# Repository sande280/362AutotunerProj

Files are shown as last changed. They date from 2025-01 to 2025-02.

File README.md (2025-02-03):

# Final Demo Video Link: https://youtube.com/shorts/DRTG0014v1s?feature=share

# Autotune and the Microcontrollers

## Project Description
- Display the frequency of the input wave and output wave using the OLED display and SPI.
- Display the autotuned note using the 7-SEG display and SPI with DMA.
- Match the read data to the nearest musical note, and output the audio via the DAC.
- Read data from earbud microphone and convert data into a single sinusoidal wave using ADC.
- Additionally, keep latency within a reasonable amount such that the process is imperceptible or nearly.

## Schematic
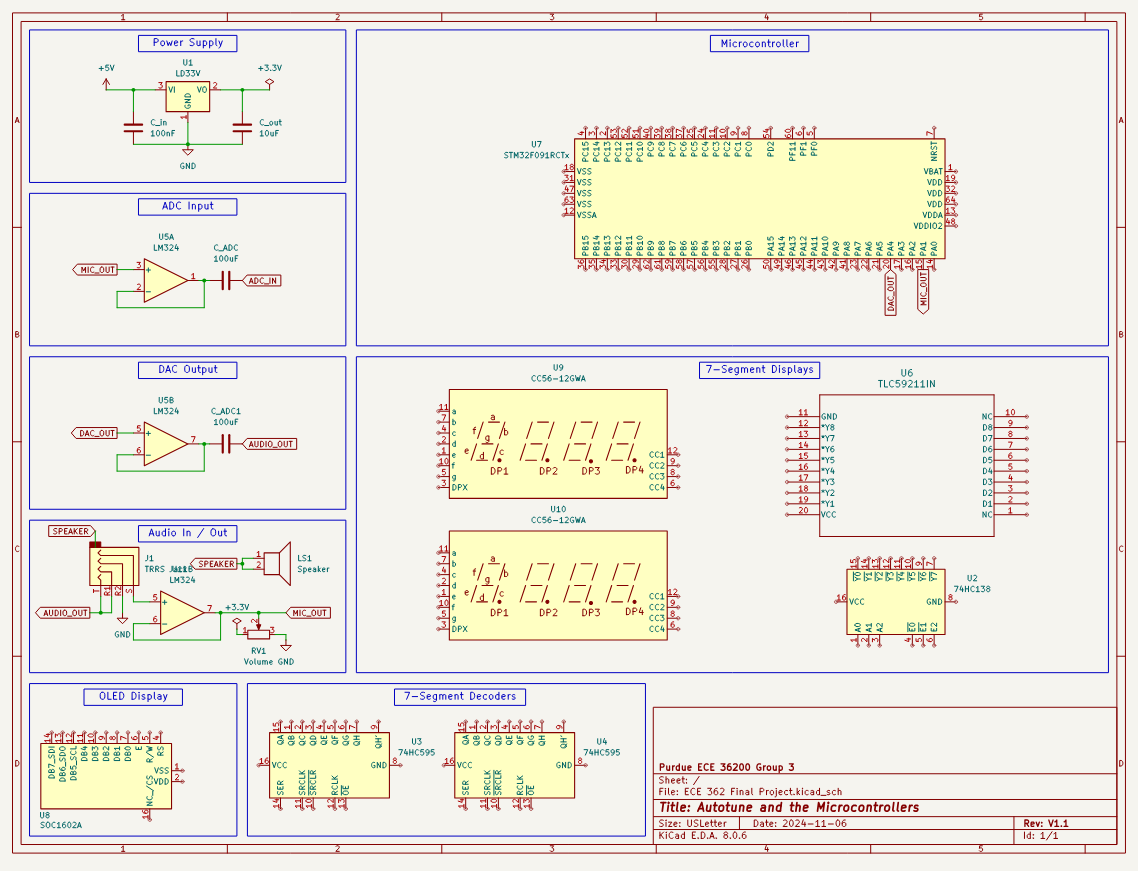
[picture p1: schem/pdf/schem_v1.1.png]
microcontroller-based autotune schematic Autotune and the Microcontrollers Schematic


## Main Features
Using the microphone on a pair of wired earbuds, we will input an audio signal (such as humming) into the ADC of the STM32. There, the microcontroller will find the nearest musical note (closest to the input frequency) and output that via the DAC to a speaker. We will also output frequency information on the OLED display, and note information on a 7-segment display.
- STM32 microcontroller
- Audio / headphone jack
- Wired headphones with mic
- Lab 4 DAC/ADC breadboard setup
- 7-segment displays
- OLED display

## External Interfaces
- SPI
- GPIO

## Internal Peripherals
- DMA
- ADC
- DAC
- SPI

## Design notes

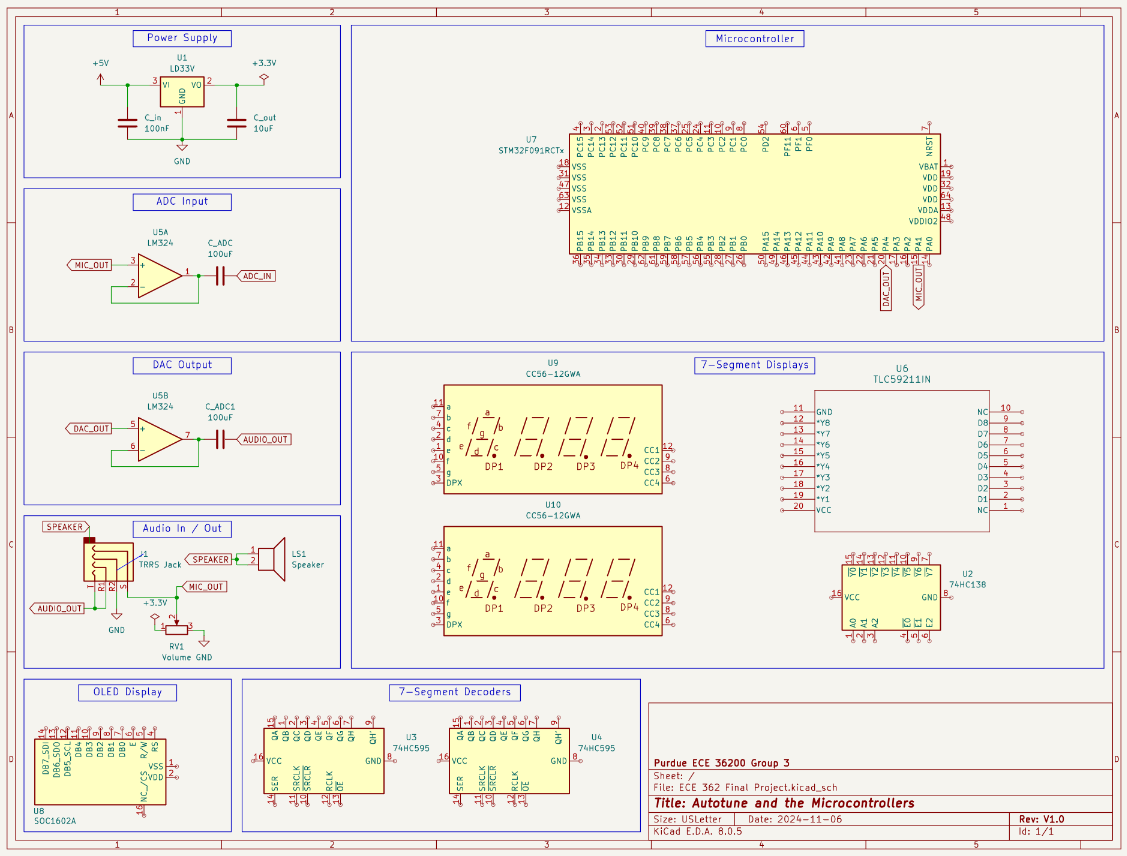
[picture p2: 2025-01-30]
schem/pdf/schem_v1.png

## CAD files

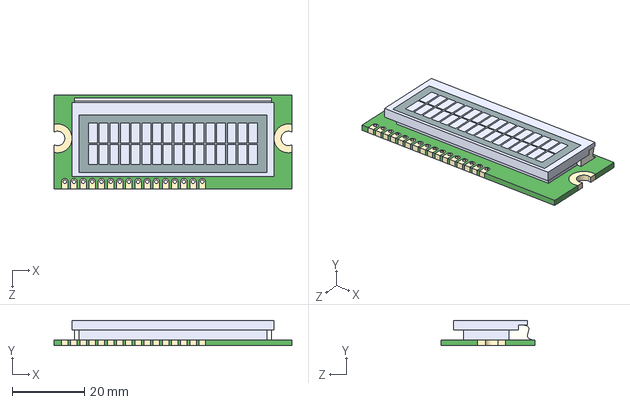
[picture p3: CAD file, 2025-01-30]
schem/KiCad Symbols/LCM_S01602DTR_M/LCM-S01602DTR_M.step
66.0 x 7.00 x 26.0 mm

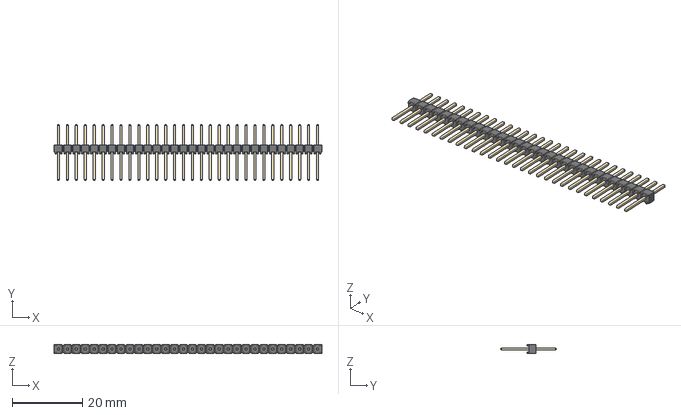
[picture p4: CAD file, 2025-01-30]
schem/KiCad Symbols/stm32f091-ref/models/HTSW-130-22-T-S.FCStd
76.2 x 16.0 x 2.49 mm
_HTSW-130-22-T-S_body
_T-1S6-15-HTSW-1--22-30-S

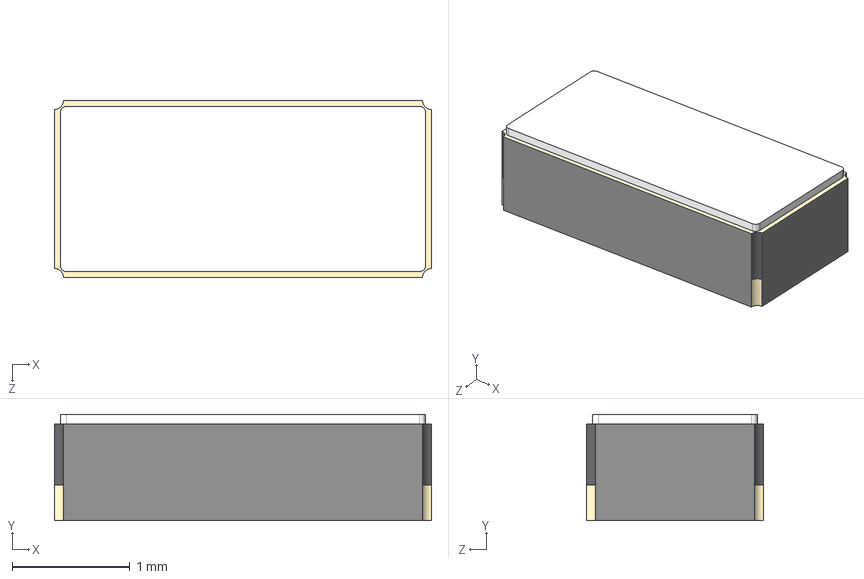
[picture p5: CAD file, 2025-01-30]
schem/KiCad Symbols/stm32f091-ref/models/ECX-.327-CDX-1293.step
3.20 x 0.9 x 1.50 mm

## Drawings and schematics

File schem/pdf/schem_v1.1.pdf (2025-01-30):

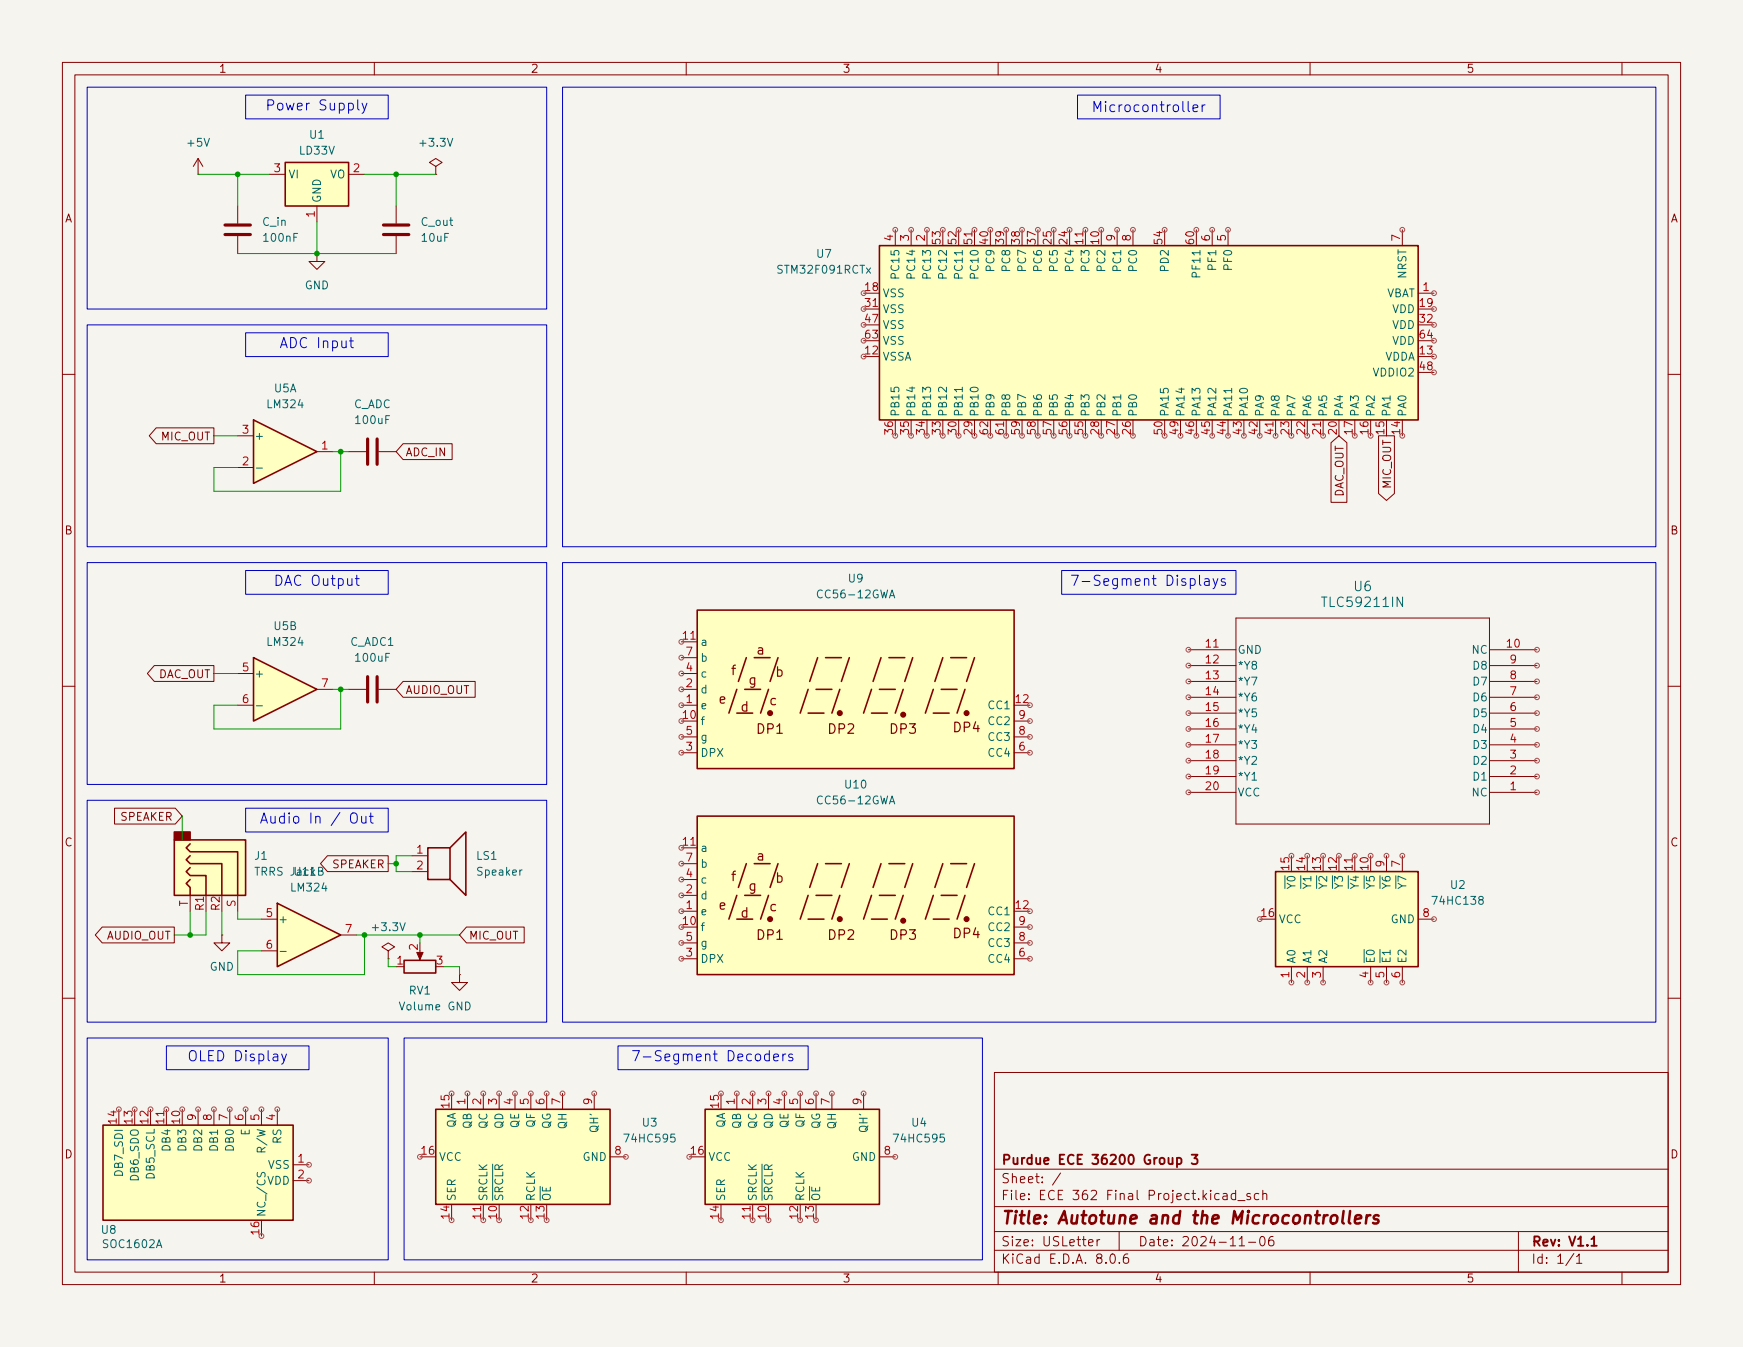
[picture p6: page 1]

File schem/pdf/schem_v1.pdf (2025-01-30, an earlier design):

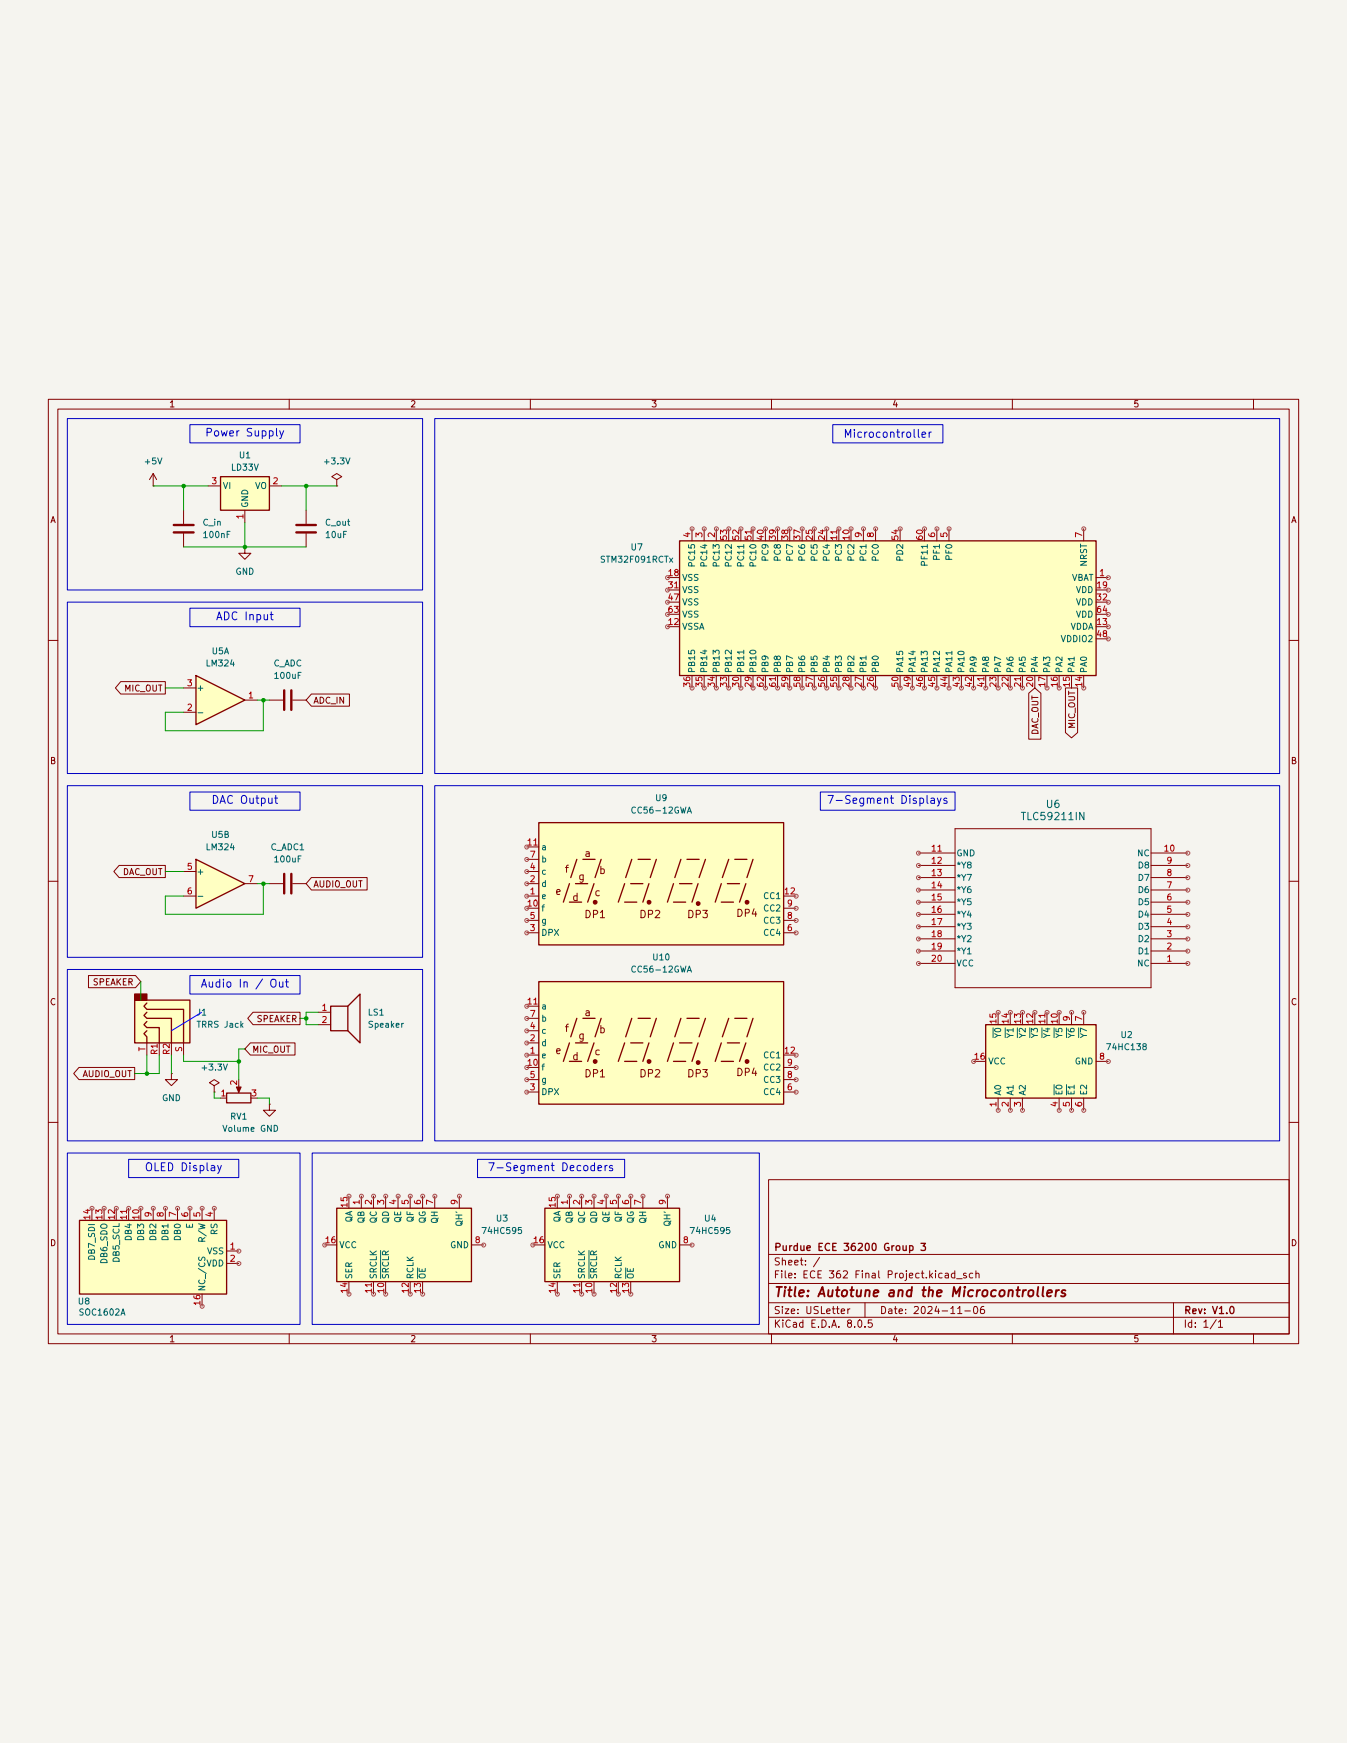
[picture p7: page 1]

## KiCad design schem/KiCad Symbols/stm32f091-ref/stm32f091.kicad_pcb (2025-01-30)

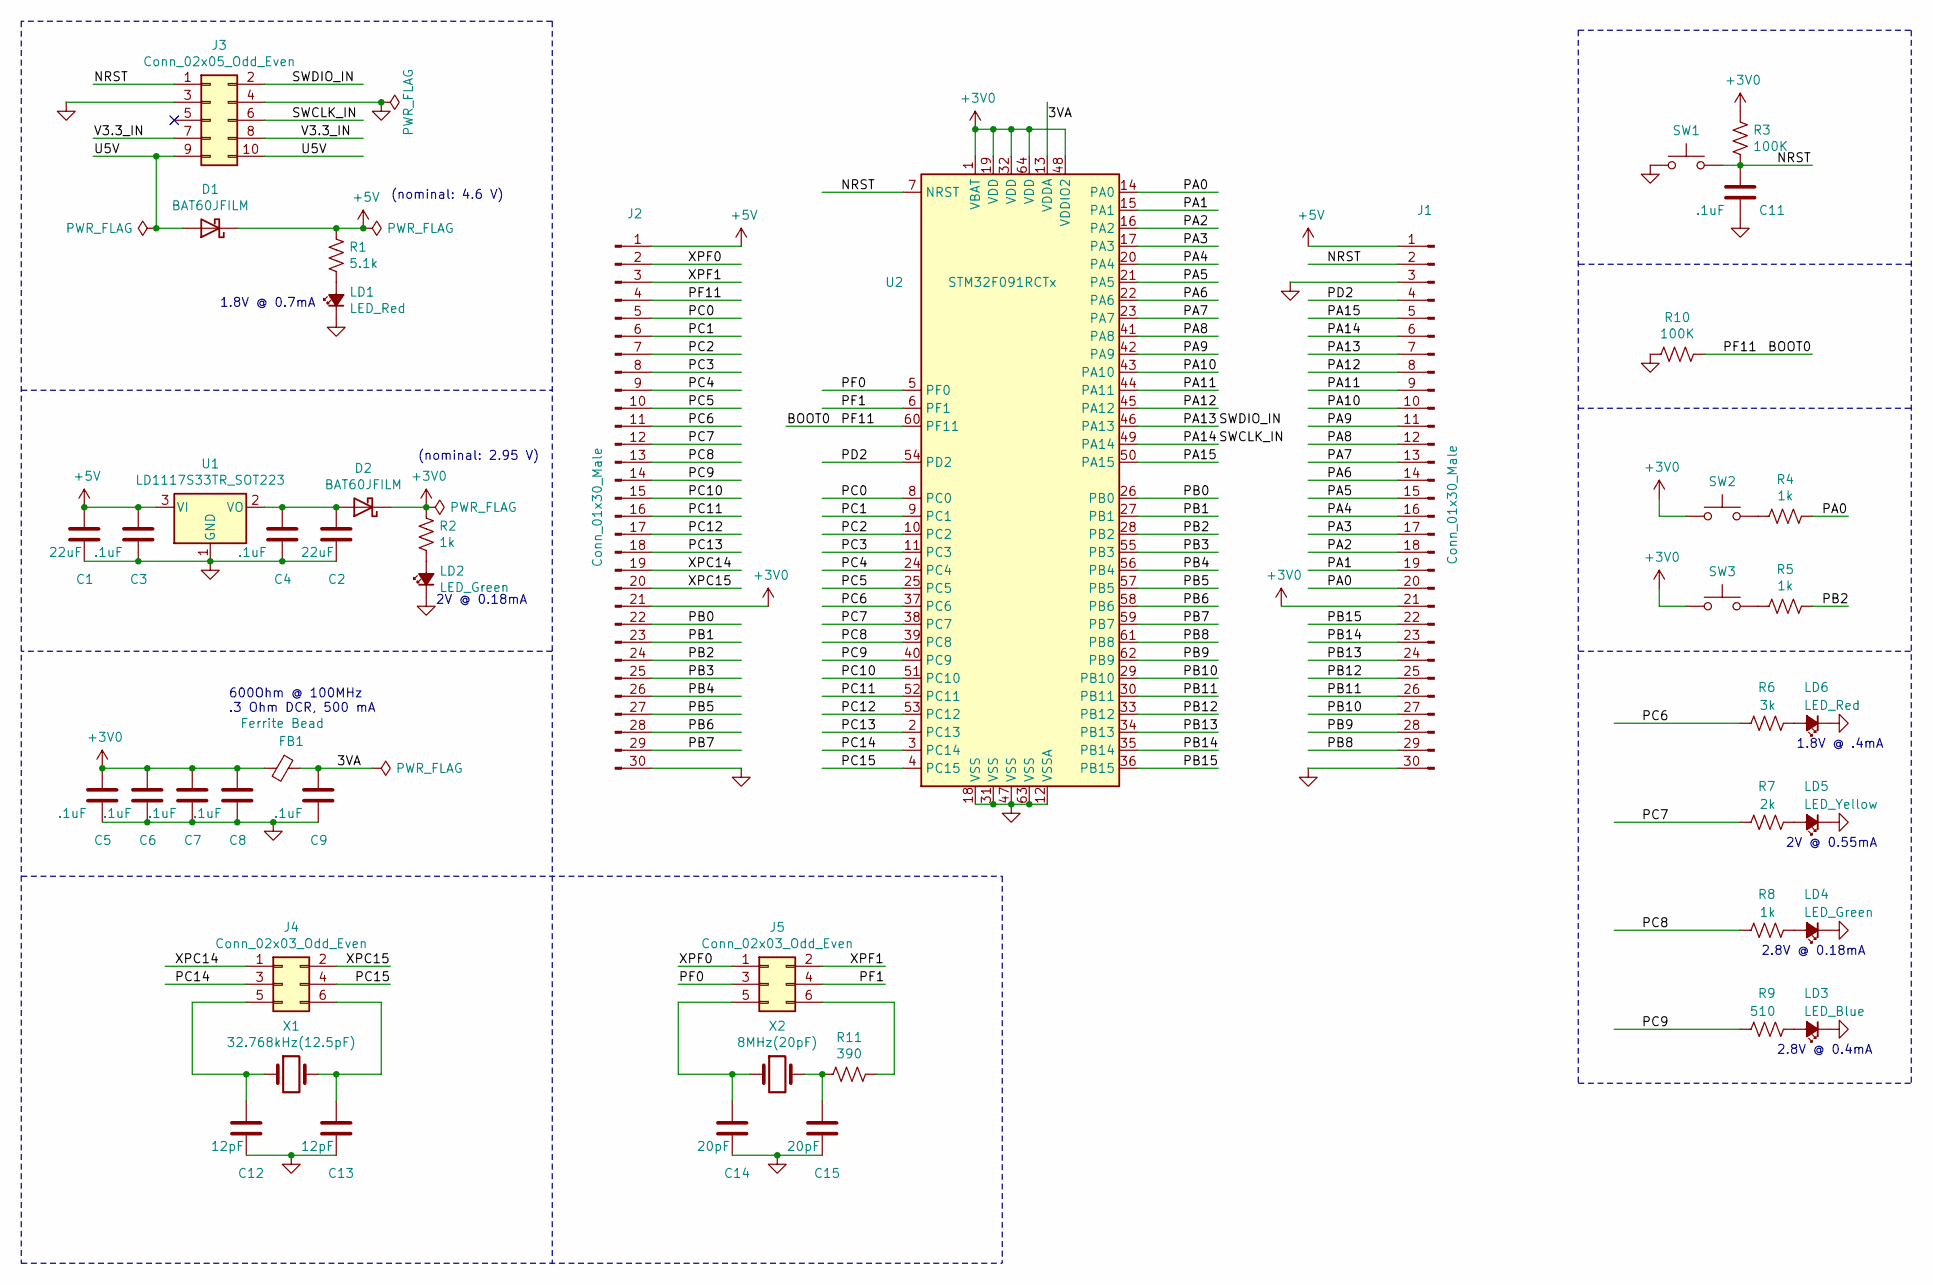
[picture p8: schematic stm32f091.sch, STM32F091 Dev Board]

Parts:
C1, C2: 22uF; C_0805_2012Metric_Pad1.15x1.40mm_HandSolder
C3, C4, C5, C6, C7, C8, C9, C11: .1uF; C_0805_2012Metric_Pad1.15x1.40mm_HandSolder
C12, C13: 12pF; C_0805_2012Metric_Pad1.15x1.40mm_HandSolder
C14, C15: 20pF; C_0805_2012Metric_Pad1.15x1.40mm_HandSolder
D1, D2: BAT60JFILM; D_SOD-323
FB1: Ferrite Bead; L_0805_2012Metric_Pad1.15x1.40mm_HandSolder
J1, J2: Conn_01x30_Male; HTSW-130-22-T-S
J3: Conn_02x05_Odd_Even; IDC-Header_2x05_P2.54mm_Vertical
J4, J5: Conn_02x03_Odd_Even; PinHeader_2x03_P1.27mm_Vertical
LD1, LD6: LED_Red; LED_0805_2012Metric
LD2, LD4: LED_Green; LED_0805_2012Metric
LD3: LED_Blue; LED_0805_2012Metric
LD5: LED_Yellow; LED_0805_2012Metric
R1: 5.1k; R_0805_2012Metric_Pad1.15x1.40mm_HandSolder
R2, R4, R5, R8: 1k; R_0805_2012Metric_Pad1.15x1.40mm_HandSolder
R3, R10: 100K; R_0805_2012Metric_Pad1.15x1.40mm_HandSolder
R6: 3k; R_0805_2012Metric_Pad1.15x1.40mm_HandSolder
R7: 2k; R_0805_2012Metric_Pad1.15x1.40mm_HandSolder
R9: 510; R_0805_2012Metric_Pad1.15x1.40mm_HandSolder
R11: 390; R_0805_2012Metric_Pad1.15x1.40mm_HandSolder; LCSC C17477
SW1, SW2, SW3: SW_Push; SW_SPST_PTS645
U1: LD1117S33TR_SOT223; SOT-223-3_TabPin2
U2: STM32F091RCTx; LQFP-64_10x10mm_P0.5mm
X1: 32.768kHz(12.5pF); ECX-.327-CDX-1293
X2: 8MHz(20pF); Crystal_SMD_3225-4Pin_3.2x2.5mm

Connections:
+3V0: C5.1, C6.1, C7.1, C8.1, D2.1 (K), FB1.2, J1.21, J2.21, R2.1, R3.1, SW2.1, SW3.1, U2.1 (VBAT), U2.19 (VDD), U2.32 (VDD), U2.48 (VDDIO2), U2.64 (VDD)
+5V: C1.1, C3.1, D1.1 (K), J1.1, J2.1, R1.1, U1.3 (VI)
/3VA: C9.1, FB1.1, U2.13 (VDDA)
/BOOT0: J2.4, R10.1, U2.60 (PF11)
/NRST: C11.1, J1.2, J3.1, R3.2, SW1.2, U2.7 (NRST)
/PA0: J1.20, R4.1, U2.14 (PA0)
/PA1: J1.19, U2.15 (PA1)
/PA2: J1.18, U2.16 (PA2)
/PA3: J1.17, U2.17 (PA3)
/PA4: J1.16, U2.20 (PA4)
/PA5: J1.15, U2.21 (PA5)
/PA6: J1.14, U2.22 (PA6)
/PA7: J1.13, U2.23 (PA7)
/PA8: J1.12, U2.41 (PA8)
/PA9: J1.11, U2.42 (PA9)
/PA10: J1.10, U2.43 (PA10)
/PA11: J1.9, U2.44 (PA11)
/PA12: J1.8, U2.45 (PA12)
/PA13: J1.7, J3.2, U2.46 (PA13)
/PA14: J1.6, J3.6, U2.49 (PA14)
/PA15: J1.5, U2.50 (PA15)
/PB0: J2.22, U2.26 (PB0)
/PB1: J2.23, U2.27 (PB1)
/PB2: J2.24, R5.1, U2.28 (PB2)
/PB3: J2.25, U2.55 (PB3)
/PB4: J2.26, U2.56 (PB4)
/PB5: J2.27, U2.57 (PB5)
/PB6: J2.28, U2.58 (PB6)
/PB7: J2.29, U2.59 (PB7)
/PB8: J1.29, U2.61 (PB8)
/PB9: J1.28, U2.62 (PB9)
/PB10: J1.27, U2.29 (PB10)
/PB11: J1.26, U2.30 (PB11)
/PB12: J1.25, U2.33 (PB12)
/PB13: J1.24, U2.34 (PB13)
/PB14: J1.23, U2.35 (PB14)
/PB15: J1.22, U2.36 (PB15)
/PC0: J2.5, U2.8 (PC0)
/PC1: J2.6, U2.9 (PC1)
/PC2: J2.7, U2.10 (PC2)
/PC3: J2.8, U2.11 (PC3)
/PC4: J2.9, U2.24 (PC4)
/PC5: J2.10, U2.25 (PC5)
/PC6: J2.11, R6.2, U2.37 (PC6)
/PC7: J2.12, R7.2, U2.38 (PC7)
/PC8: J2.13, R8.2, U2.39 (PC8)
/PC9: J2.14, R9.2, U2.40 (PC9)
/PC10: J2.15, U2.51 (PC10)
/PC11: J2.16, U2.52 (PC11)
/PC12: J2.17, U2.53 (PC12)
/PC13: J2.18, U2.2 (PC13)
/PC14: J4.3, U2.3 (PC14)
/PC15: J4.4, U2.4 (PC15)
/PD2: J1.4, U2.54 (PD2)
/PF0: J5.3, U2.5 (PF0)
/PF1: J5.4, U2.6 (PF1)
/U5V: D1.2 (A), J3.9, J3.10
/V3.3_IN: J3.7, J3.8
/XPC14: J2.19, J4.1
/XPC15: J2.20, J4.2
/XPF0: J2.2, J5.1
/XPF1: J2.3, J5.2
GND: C1.2, C2.2, C3.2, C4.2, C5.2, C6.2, C7.2, C8.2, C9.2, C11.2, C12.2, C13.2, C14.2, C15.2, J1.3, J1.30, J2.30, J3.3, J3.4, LD1.1 (K), LD2.1 (K), LD3.1 (K), LD4.1 (K), LD5.1 (K), LD6.1 (K), R10.2, SW1.1, U1.1 (GND), U2.12 (VSSA), U2.18 (VSS), U2.31 (VSS), U2.47 (VSS), U2.63 (VSS)
unnamed: C2.1, C4.1, D2.2 (A), U1.2 (VO)
unnamed: C12.1, J4.5, X1.1
unnamed: C13.1, J4.6, X1.2
unnamed: C14.1, J5.5, X2.1
unnamed: C15.1, R11.2, X2.2
unnamed: J5.6, R11.1
unnamed: LD1.2 (A), R1.2
unnamed: LD2.2 (A), R2.2
unnamed: LD3.2 (A), R9.1
unnamed: LD4.2 (A), R8.1
unnamed: LD5.2 (A), R7.1
unnamed: LD6.2 (A), R6.1
unnamed: R4.2, SW2.2
unnamed: R5.2, SW3.2

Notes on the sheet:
1.8V @ 0.7mA
2V @ 0.18mA
2.8V @ 0.18mA
2.8V @ 0.4mA
600Ohm @ 100MHz .3 Ohm DCR, 500 mA
1.8V @ .4mA
2V @ 0.55mA
(nominal: 4.6 V)
(nominal: 2.95 V)

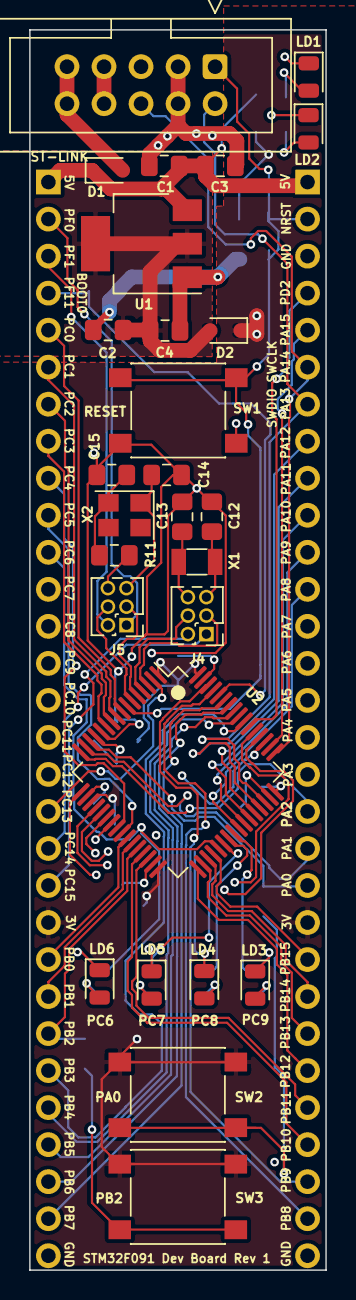
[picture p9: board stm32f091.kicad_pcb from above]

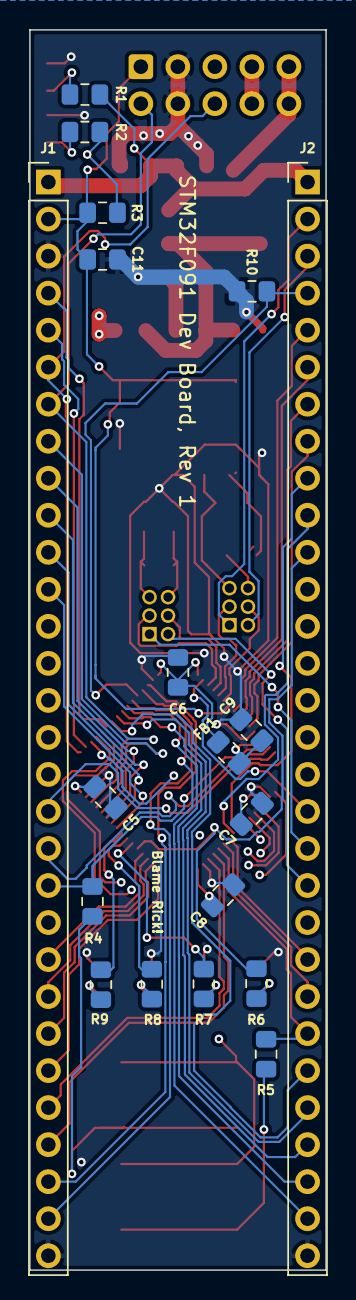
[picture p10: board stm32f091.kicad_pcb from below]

Board: 4 copper layers, 20.3 x 85.1 mm, 46 parts (19 on the bottom side), 77 nets.

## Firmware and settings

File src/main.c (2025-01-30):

#include "stm32f0xx.h"
#include <math.h>
#include <stdio.h>

#ifndef M_PI
    #define M_PI 3.141592
#endif

void nano_wait(unsigned int);
void internal_clock();
void drive_column(int);
int  read_rows();
void update_history(int col, int rows);
char get_key_event(void);
char get_keypress(void);
void show_keys(void);
void spi1_dma_display1(const char *str);
void spi1_dma_display2(const char *str);
void print(const char str[]);

void autotune_algorithm(uint64_t note, char** tuned_name, uint32_t* tuned_frequency);
int abs_fn(int n);


//============================================================================
// Input raw note via the ADC
//============================================================================
// sampling parameters
#define BUFFER_SIZE 1024
#define SAMPLE_RATE 24000
uint16_t bufferIndex = 0;
int adcBuffer[BUFFER_SIZE];
uint32_t frequency;

void setup_adc(void) {
    // enable RCC clock on GPIO A
    RCC->AHBENR |= RCC_AHBENR_GPIOAEN;

    // configure ADC_IN1 to be in analog mode (pin PA1)
    GPIOA->MODER |= 0xc;

    // enable ADC clock
    RCC->APB2ENR |= RCC_APB2ENR_ADCEN;

    // continuous mode
    ADC1->CFGR1 |= ADC_CFGR1_CONT;

    // enable high-speed 14MHz clock (HSI14)
    RCC->CR2 |= RCC_CR2_HSI14ON;

    // wait for HSI14 to be ready
    while(!(RCC->CR2 & RCC_CR2_HSI14RDY));

    // enable ADC by setting ADEN bit
    ADC1->CR |= ADC_CR_ADEN;

    // wait for ADC1 to be ready
    while(!(ADC1->ISR & ADC_ISR_ADRDY));

    // select channel for ADC_IN1
    ADC1->CHSELR |= 1 << 1;

    // wait for ADC1 to be ready
    while(!(ADC1->ISR & ADC_ISR_ADRDY));

    ADC1->CR |= ADC_CR_ADSTART;
}

int note = 0;

void TIM2_IRQHandler(void) {
    TIM2->SR &= ~TIM_SR_UIF;
    while (!(ADC1->ISR & ADC_ISR_EOC));

    adcBuffer[bufferIndex] = ADC1->DR;
    
    note = adcBuffer[bufferIndex];
    
    bufferIndex = (bufferIndex + 1) % BUFFER_SIZE;
}

void init_tim2(void) {
    // enable RCC clock for TIM2
    RCC->APB1ENR |= RCC_APB1ENR_TIM2EN;

    // lower TIM2 priority
    NVIC_SetPriority(TIM2_IRQn, 3);

    // prescale to 4.8MHz
    TIM2->PSC = 9;
    // auto-reload register to 48kHz
    TIM2->ARR = 199;

    // enable UIE bit in the DIER
    TIM2->DIER |= TIM_DIER_UIE;

    // enable TIM2 interrupt in NVIC
    NVIC_EnableIRQ(TIM2_IRQn);

    // enable TIM2 by setting CEN bit in TIM2_CR1
    TIM2->CR1 |= TIM_CR1_CEN;
}


uint64_t dominantFrequency; 

void performFFT(void) {
    // arrays to hold real and imaginary parts

    float real[BUFFER_SIZE];
    float imag[BUFFER_SIZE];

    // Copy adcBuffer into real part, set imaginary part to zero
    for (int i = 0; i < BUFFER_SIZE; i++) {
        real[i] = (float)adcBuffer[i];
        imag[i] = 0.0f;
    }

    // Bit-reversal 
    int n = BUFFER_SIZE;
    int j = 0;
    for (int i = 0; i < n; i++) {
        if (i < j) {
            // Swap real[i] and real[j]
            float tempReal = real[i];
            real[i] = real[j];
            real[j] = tempReal;

            // Swap imag[i] and imag[j]
            float tempImag = imag[i];
            imag[i] = imag[j];
            imag[j] = tempImag;
        }
        int m = n / 2;
        while (j >= m && m > 0) {
            j -= m;
            m /= 2;
        }
        j += m;
    }

    // Danielson-Lanczos algorithm
    int nu = 10; // Since BUFFER_SIZE is 256, log2(256) = 8
    for (int s = 1; s <= nu; s++) {
        int m = 1 << s;
        int m2 = m / 2;
        float theta = -M_PI / m2;
        float wpr = cosf(theta);
        float wpi = sinf(theta);

        for (int k = 0; k < n; k += m) {
            float wr = 1.0f;
            float wi = 0.0f;

            for (int j = 0; j < m2; j++) {
                int t = k + j + m2;
                int u = k + j;

                float tr = wr * real[t] - wi * imag[t];
                float ti = wr * imag[t] + wi * real[t];

                real[t] = real[u] - tr;
                imag[t] = imag[u] - ti;

                real[u] += tr;
                imag[u] += ti;

                // Update the twiddle factors
                float tempWr = wr;
                wr = tempWr * wpr - wi * wpi;
                wi = tempWr * wpi + wi * wpr;
            }
        }
    }

    // Find magnitude spectrum and find dominant frequency
    float maxMagnitude = 0.0f;
    int dominantBin = 0;
    for (int i = 1; i < BUFFER_SIZE / 2; i++) {
        // Find magnitude
        float magnitude = real[i] * real[i] + imag[i] * imag[i];

        if (magnitude > maxMagnitude) {
            maxMagnitude = magnitude;
            dominantBin = i;
        }
    }

    // Find dominant frequency and scale by 10000

    dominantFrequency = (dominantBin * SAMPLE_RATE) / BUFFER_SIZE;
}

//============================================================================
// Autotune the note
//============================================================================

#define OCTAVES 9
#define NOTES_PER_OCTAVE 12

const int note_frequencies[OCTAVES][NOTES_PER_OCTAVE] = {
    {163500, 173200, 183500, 194500, 206000, 218300, 231200, 245000, 259600, 275000, 291400, 308700},
    {327000, 346500, 367100, 388900, 412000, 436500, 462500, 490000, 519100, 550000, 582700, 617400},
    {654100, 693000, 734200, 777800, 824100, 873100, 925000, 980000, 1038300, 1100000, 1165400, 1234700},
    {1308100, 1385900, 1468300, 1555600, 1648100, 1746100, 1850000, 1960000, 2076500, 2200000, 2330800, 2469400},
    {2616300, 2771800, 2936600, 3111300, 3296300, 3492300, 3699900, 3920000, 4153000, 4400000, 4661600, 4938800},
    {5232500, 5543700, 5873300, 6222500, 6592500, 6984600, 7399900, 7839900, 8306100, 8800000, 9323300, 9877700},
    {10465000, 11087300, 11746600, 12445100, 13185100, 13969100, 14799800, 15679800, 16612200, 17600000, 18646600, 19755300},
    {20930000, 22174600, 23493200, 24890200, 26370200, 27938300, 29599600, 31359600, 33224400, 35200000, 37293100, 39510700},
    {41860100, 44349200, 46986300, 49780300, 52740400, 55876500, 59199100, 62719300, 66448800, 70400000, 74586200, 79021300} 
};

void autotune_algorithm(uint64_t note, char** tuned_name, uint32_t* tuned_frequency) {
    char* name_arr[NOTES_PER_OCTAVE] = {"C ", "Db", "D ", "Eb", "E ", "F ", "Gb", "G ", "Ab", "A ", "Bb", "B "};

    int octave_reduce = 0; // number of times frequency is halved
    uint64_t converted_note = note;
    while (converted_note > 317900) { // halfway between octave 0 B and octave 1 C
        converted_note /= 2;
        octave_reduce++;
    }

    // Find the nearest note
    double min_difference = abs_fn(converted_note - note_frequencies[0][0]);
    int note_idx = 0;

    for (int i = 1; i < NOTES_PER_OCTAVE; i++) {
        double temp_difference = abs_fn(converted_note - note_frequencies[0][i]);
        if (temp_difference < min_difference) {
            min_difference = temp_difference;
            note_idx = i;
        }
    }
    
    *tuned_name = name_arr[note_idx];
    *tuned_frequency = note_frequencies[octave_reduce][note_idx];
}

int abs_fn(int n) {
    return (n < 0) ? -n : n;
}

//============================================================================

// Parameters for the wavetable size and expected synthesis rate.
#define N 1000
#define RATE 20000
int volume = 2048;
short int wavetable[N];
int step0 = 0;
int offset0 = 0;
int step1 = 0;
int offset1 = 0;

//===========================================================================
// init_wavetable()
// Write the pattern for a complete cycle of a sine wave into the
// wavetable[] array.
//===========================================================================
void init_wavetable(void) {
    for(int i=0; i < N; i++)
        wavetable[i] = 32767 * sin(2 * M_PI * i / N);
}

//============================================================================
// set_freq()
//============================================================================
void set_freq(int chan, float f) {
    if (chan == 0) {
        if (f == 0.0) {
            step0 = 0;
            offset0 = 0;
        } else
            step0 = (f * N / RATE) * (1<<16);
    }
    if (chan == 1) {
        if (f == 0.0) {
            step1 = 0;
            offset1 = 0;
        } else
            step1 = (f * N / RATE) * (1<<16);
    }
}

//============================================================================
// setup_dac()
//============================================================================
void setup_dac(void) {
    //DAC_OUT1 is PA4
    RCC->AHBENR |= RCC_AHBENR_GPIOAEN; // enable the clock to GPIO A
    GPIOA->MODER |= 0b1100000000; // set DAC_OUT1 to analog mode
    RCC->APB1ENR |= RCC_APB1ENR_DACEN; // enable the clock for DAC peripheral
    DAC->CR |= 0b000101; // Select TIM6 TRGO trigger and enable the trigger for the DAC, then enable DAC
}

//============================================================================
// Timer 6 ISR
//============================================================================
// Write the Timer 6 ISR here.  Be sure to give it the right name.
void TIM6_DAC_IRQHandler(void) {
    TIM6->SR &= ~TIM_SR_UIF; //acknowledge the interrupt
    set_freq(0,(float)frequency / 10000);
    offset0 += step0;
    offset1 += step1;
    if (offset0 >= (N << 16)) {
        offset0 -= (N << 16);
    }
    if (offset1 >= (N << 16)) {
        offset1 -= (N << 16);
    }
    int samp = wavetable[offset0 >> 16] + wavetable[offset1 >> 16];
    samp *= volume;
    samp = samp >> 17;
    samp += 2048;
    DAC->DHR12R1 = samp;
}

//============================================================================
// init_tim6()
//============================================================================
void init_tim6(void) {
    RCC->APB1ENR |= RCC_APB1ENR_TIM6EN;
    TIM6->PSC = (48000000 / 1000000) - 1; // gets timer to 1 MHz
    TIM6->ARR = (1000000 / RATE) - 1; // gets timer to RATE Hz
    TIM6->DIER |= TIM_DIER_UIE; // enable update interrupt every time counter reaches ARR value
    NVIC_EnableIRQ(TIM6_DAC_IRQn); // enable interrupt
   
    TIM6->CR2 |= 0b0100000; // MMS field for Update event
    TIM6->CR1 |= TIM_CR1_CEN;
}


//============================================================================
// Display note using the 7-segment display
// nOtE__XY, where X is the note letter and Y is sharp or flat
//============================================================================
uint16_t msg[8] = { 0x0000,0x0100,0x0200,0x0300,0x0400,0x0500,0x0600,0x0700 };
uint8_t col;

void init_tim7(void) {
    // enable RCC clock for TIM7
    RCC->APB1ENR |= RCC_APB1ENR_TIM7EN;

    // prescale to 10kHz
    TIM7->PSC = 4799;
    // auto-reload register to 1kHz
    TIM7->ARR = 9;

    // enable UIE bit in the DIER
    TIM7->DIER |= TIM_DIER_UIE;

    // enable TIM7 interrupt in NVIC
    NVIC_EnableIRQ(TIM7_IRQn);

    // enable TIM7 by setting CEN bit in TIM7_CR1
    TIM7->CR1 |= TIM_CR1_CEN;
}

void TIM7_IRQHandler(void) {
    // acknowledge timer interrupt by clearing UIF bit
    TIM7->SR &= ~TIM_SR_UIF;

    // update button history
    int rows = read_rows();
    update_history(col, rows);
    col = (col + 1) & 3;
    drive_column(col);
}

void init_spi2(void) {
    // enable RCC clock for GPIOB and SPI2
    RCC->AHBENR |= RCC_AHBENR_GPIOBEN;
    RCC->APB1ENR |= RCC_APB1ENR_SPI2EN;

    // pins PB12, PB13, PB15 set to alt function mode
    GPIOB->MODER &= ~(0xFFFFFFFF);
    GPIOB->MODER |= GPIO_MODER_MODER12_1 | GPIO_MODER_MODER13_1 | GPIO_MODER_MODER15_1;

    // ensure SPI2 is disabled
    SPI2->CR1 &= ~SPI_CR1_SPE;

    // set baud rate to lowest possible setting
    SPI2->CR1 |= SPI_CR1_BR_2 | SPI_CR1_BR_1 | SPI_CR1_BR_0;

    // set data frame format to 16-bit
    SPI2->CR2 |= (15 << SPI_CR2_DS_Pos);

    // configure SPI2 as master device
    SPI2->CR1 |= SPI_CR1_MSTR;

    // set SS output enable and enable NSSP
    SPI2->CR2 |= SPI_CR2_SSOE | SPI_CR2_NSSP;

    // enable DMA transmit on buffer empty
    SPI2->CR2 |= SPI_CR2_TXDMAEN;

    // enable SPI2 peripheral
    SPI2->CR1 |= SPI_CR1_SPE;
}

void spi2_setup_dma(void) {
    // enable RCC clock for DMA1
    RCC->AHBENR |= RCC_AHBENR_DMA1EN;

    // ensure DMA channel is disabled
    DMA1_Channel5->CCR &= ~DMA_CCR_EN;

    // setup channel memory address register
    DMA1_Channel5->CMAR = (uint32_t) (msg);

    // setup channel peripheral address register
    DMA1_Channel5->CPAR = (uint32_t) &(SPI2->DR);

    // setup channel number of data to transfer register
    DMA1_Channel5->CNDTR = 8;

    // setup copy direction
    DMA1_Channel5->CCR |= DMA_CCR_DIR; // read from memory

    // setup memory increment
    DMA1_Channel5->CCR |= DMA_CCR_MINC;

    // setup memory datum size as 16 bits
    DMA1_Channel5->CCR |= DMA_CCR_MSIZE_0; // 00: 8-bit, --01: 16-bit--, 10: 32-bit

    // setup peripheral datum size as 16 bits
    DMA1_Channel5->CCR |= DMA_CCR_PSIZE_0; // 00: 8-bit, --01: 16-bit--, 10: 32-bit

    // setup channel for circular operation
    DMA1_Channel5->CCR |= DMA_CCR_CIRC; 

    // enable SPI2 bit
    SPI2->CR2 |= SPI_CR2_TXEIE;
}

void spi2_enable_dma(void) {
    DMA1_Channel5->CCR |= DMA_CCR_EN;
}

//============================================================================
// Display input and output note frequency using the OLED display
// Input:  456.28hz
// Output: 440.00hz
//============================================================================
uint16_t display[34] = {
        0x002, // Command to set the cursor at the first position line 1
        0x200+'E', 0x200+'C', 0x200+'E', 0x200+'3', 0x200+'6', + 0x200+'2', 0x200+' ', 0x200+'i',
        0x200+'s', 0x200+' ', 0x200+'t', 0x200+'h', + 0x200+'e', 0x200+' ', 0x200+' ', 0x200+' ',
        0x0c0, // Command to set the cursor at the first position line 2
        0x200+'c', 0x200+'l', 0x200+'a', 0x200+'s', 0x200+'s', + 0x200+' ', 0x200+'f', 0x200+'o',
        0x200+'r', 0x200+' ', 0x200+'y', 0x200+'o', + 0x200+'u', 0x200+'!', 0x200+' ', 0x200+' ',
};

void init_spi1(void) {
    // enable RCC clock for GPIOA and SPI1
    RCC->AHBENR |= RCC_AHBENR_GPIOAEN;
    RCC->APB2ENR |= RCC_APB2ENR_SPI1EN;

    // pins PA15, PA5, PA7 set to alt function mode
    GPIOA->MODER &= ~(0xFFFFFFFF);
    GPIOA->MODER |= 0x28000000; // restore important pin values
    GPIOA->MODER |= GPIO_MODER_MODER15_1 | GPIO_MODER_MODER5_1 | GPIO_MODER_MODER7_1;

    // ensure SPI1 is disabled
    SPI1->CR1 &= ~SPI_CR1_SPE;

    // set baud rate to lowest possible setting
    SPI1->CR1 |= SPI_CR1_BR_2 | SPI_CR1_BR_1 | SPI_CR1_BR_0;

    // set data frame format to 10-bit
    SPI1->CR2 |= (15 << SPI_CR2_DS_Pos);
    SPI1->CR2 &= ~(6 << SPI_CR2_DS_Pos);

    // configure SPI1 as master device
    SPI1->CR1 |= SPI_CR1_MSTR;

    // set SS output enable and enable NSSP
    SPI1->CR2 |= SPI_CR2_SSOE | SPI_CR2_NSSP;

    // enable DMA transmit on buffer empty
    SPI1->CR2 |= SPI_CR2_TXDMAEN;

    // enable SPI1 peripheral
    SPI1->CR1 |= SPI_CR1_SPE;
}

void spi_cmd(unsigned int data) {
    // wait until SPI1 TX buffer is empty
    while (!(SPI1->SR & SPI_SR_TXE)) {;}

    // send data
    SPI1->DR = data;
}

void spi_data(unsigned int data) {
    // calls spi_cmd with data
    spi_cmd(data | 0x200);
}

void spi1_init_oled() {
    // wait 1 ms
    nano_wait(1000000);

    // send initialization commands
    spi_cmd(0x38);       // function set
    spi_cmd(0x08);       // display off
    spi_cmd(0x01);       // clear display
    nano_wait(2000000);  // wait for 2 ms
    spi_cmd(0x06);       // set entry mode
    spi_cmd(0x02);       // move cursor to home position
    spi_cmd(0x0C);       // display on
}

void spi1_setup_dma(void) {
    // enable RCC clock for DMA1
    RCC->AHBENR |= RCC_AHBENR_DMA1EN;

    // ensure DMA channel is disabled
    DMA1_Channel3->CCR &= ~DMA_CCR_EN;

    // setup channel memory address register
    DMA1_Channel3->CMAR = (uint32_t) (display);

    // setup channel peripheral address register
    DMA1_Channel3->CPAR = (uint32_t) &(SPI1->DR);

    // setup channel number of data to transfer register
    DMA1_Channel3->CNDTR = 34;

    // setup copy direction
    DMA1_Channel3->CCR |= DMA_CCR_DIR; // read from memory

    // setup memory increment
    DMA1_Channel3->CCR |= DMA_CCR_MINC;

    // setup memory datum size as 16 bits
    DMA1_Channel3->CCR |= DMA_CCR_MSIZE_0; // 00: 8-bit, --01: 16-bit--, 10: 32-bit

    // setup peripheral datum size as 16 bits
    DMA1_Channel3->CCR |= DMA_CCR_PSIZE_0; // 00: 8-bit, --01: 16-bit--, 10: 32-bit

    // setup channel for circular operation
    DMA1_Channel3->CCR |= DMA_CCR_CIRC; 

    // enable SPI1 bit
    SPI1->CR2 |= SPI_CR2_TXDMAEN;
}

void spi1_enable_dma(void) {
    DMA1_Channel3->CCR |= DMA_CCR_EN;
}

//============================================================================
// Run the program!
//============================================================================
char* name = "A ";

char note_display[8] = "Note A ";
char frequency_str[16];
char note_str[16];

int main(void)
{
    // setup
    internal_clock();

    // enable 7-SEG display
    init_spi2();
    spi2_setup_dma();
    spi2_enable_dma();
    // enable OLED display
    init_spi1();
    spi1_init_oled();
    spi1_setup_dma();
    spi1_enable_dma();
    // Enable ADC
    setup_adc();
    init_tim2();
    

    // Enable DAC
    init_wavetable();
    setup_dac();
    init_tim6();

    while(1) {
        if (bufferIndex == BUFFER_SIZE - 1) {
            performFFT();
            // Run autotune algorithm to get the note and frequency
            autotune_algorithm(dominantFrequency * 10000, &name, &frequency);

            // Display on 7-SEG
            note_display[5] = name[0];
            note_display[6] = name[1];
            print(note_display);

            // Display on OLED
            sprintf(frequency_str, "Output: %ldhz", frequency / 10000);
            sprintf(note_str, "Input: %dhz", dominantFrequency);

            spi1_dma_display1(note_str);
            spi1_dma_display2(frequency_str);
        }
    }

}

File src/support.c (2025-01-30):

#include "stm32f0xx.h"
#include <string.h> // for memmove()
#include <stdlib.h> // for srandom() and random()
#include <stdio.h>

void nano_wait(unsigned int n) {
    asm(    "        mov r0,%0\n"
            "repeat: sub r0,#83\n"
            "        bgt repeat\n" : : "r"(n) : "r0", "cc");
}

const char font[] = {
    0x01, 0x01, 0x01, 0x01, 0x01, 0x01, 0x01, 0x01,
    0x01, 0x01, 0x01, 0x01, 0x01, 0x01, 0x01, 0x01,
    0x01, 0x01, 0x01, 0x01, 0x01, 0x01, 0x01, 0x01,
    0x01, 0x01, 0x01, 0x01, 0x01, 0x01, 0x01, 0x01,
    0x00, // 32: space
    0x86, // 33: exclamation
    0x22, // 34: double quote
    0x76, // 35: octothorpe
    0x00, // dollar
    0x00, // percent
    0x00, // ampersand
    0x20, // 39: single quote
    0x39, // 40: open paren
    0x0f, // 41: close paren
    0x49, // 42: asterisk
    0x00, // plus
    0x10, // 44: comma
    0x40, // 45: minus
    0x80, // 46: period
    0x00, // slash
    // digits
    0x3f, 0x06, 0x5b, 0x4f, 0x66, 0x6d, 0x7d, 0x07, 0x7f, 0x67,
    // seven unknown
    0x01, 0x01, 0x01, 0x01, 0x01, 0x01, 0x01,
    // Uppercase
    0x77, 0x7c, 0x39, 0x5e, 0x79, 0x71, 0x6f, 0x76, 0x30, 0x1e, 0x00, 0x38, 0x00,
    0x37, 0x3f, 0x73, 0x7b, 0x31, 0x6d, 0x78, 0x3e, 0x00, 0x00, 0x00, 0x6e, 0x00,
    0x39, // 91: open square bracket
    0x00, // backslash
    0x0f, // 93: close square bracket
    0x00, // circumflex
    0x08, // 95: underscore
    0x20, // 96: backquote
    // Lowercase
    0x5f, 0x7c, 0x58, 0x5e, 0x79, 0x71, 0x6f, 0x74, 0x10, 0x0e, 0x00, 0x30, 0x00,
    0x54, 0x5c, 0x73, 0x7b, 0x50, 0x6d, 0x78, 0x1c, 0x00, 0x00, 0x00, 0x6e, 0x00
};

extern uint16_t msg[8];

void set_digit_segments(int digit, char val) {
    msg[digit] = (digit << 8) | val;
}

void print(const char str[])
{
    const char *p = str;
    for(int i=0; i<8; i++) {
        if (*p == '\0') {
            msg[i] = (i<<8);
        } else {
            msg[i] = (i<<8) | font[*p & 0x7f] | (*p & 0x80);
            p++;
        }
    }
}

void printfloat(float f)
{
    char buf[10];
    snprintf(buf, 10, "%f", f);
    for(int i=1; i<10; i++) {
        if (buf[i] == '.') {
            // Combine the decimal point into the previous digit.
            buf[i-1] |= 0x80;
            memcpy(&buf[i], &buf[i+1], 10-i-1);
        }
    }
    print(buf);
}

void append_segments(char val) {
    for (int i = 0; i < 7; i++) {
        set_digit_segments(i, msg[i+1] & 0xff);
    }
    set_digit_segments(7, val);
}

void clear_display(void) {
    for (int i = 0; i < 8; i++) {
        msg[i] = msg[i] & 0xff00;
    }
}

// 16 history bytes.  Each byte represents the last 8 samples of a button.
uint8_t hist[16];
char queue[2];  // A two-entry queue of button press/release events.
int qin;        // Which queue entry is next for input
int qout;       // Which queue entry is next for output

const char keymap[] = "DCBA#9630852*741";

void push_queue(int n) {
    queue[qin] = n;
    qin ^= 1;
}

char pop_queue() {
    char tmp = queue[qout];
    queue[qout] = 0;
    qout ^= 1;
    return tmp;
}

void update_history(int c, int rows)
{
    // We used to make students do this in assembly language.
    for(int i = 0; i < 4; i++) {
        hist[4*c+i] = (hist[4*c+i]<<1) + ((rows>>i)&1);
        if (hist[4*c+i] == 0x01)
            push_queue(0x80 | keymap[4*c+i]);
        if (hist[4*c+i] == 0xfe)
            push_queue(keymap[4*c+i]);
    }
}

void drive_column(int c)
{
    GPIOC->BSRR = 0xf00000 | ~(1 << (c + 4));
}

int read_rows()
{
    return (~GPIOC->IDR) & 0xf;
}

char get_key_event(void) {
    for(;;) {
        asm volatile ("wfi");   // wait for an interrupt
        if (queue[qout] != 0)
            break;
    }
    return pop_queue();
}

char get_keypress() {
    char event;
    for(;;) {
        // Wait for every button event...
        event = get_key_event();
        // ...but ignore if it's a release.
        if (event & 0x80)
            break;
    }
    return event & 0x7f;
}

void show_keys(void)
{
    char buf[] = "        ";
    for(;;) {
        char event = get_key_event();
        memmove(buf, &buf[1], 7);
        buf[7] = event;
        print(buf);
    }
}

// Turn on the dot of the rightmost display element.
void dot()
{
    msg[7] |= 0x80;
}

extern uint16_t display[34];
void spi1_dma_display1(const char *str)
{
    for(int i=0; i<16; i++) {
        if (str[i])
            display[i+1] = 0x200 + str[i];
        else {
            // End of string.  Pad with spaces.
            for(int j=i; j<16; j++)
                display[j+1] = 0x200 + ' ';
            break;
        }
    }
}

void spi1_dma_display2(const char *str)
{
    for(int i=0; i<16; i++) {
        if (str[i])
            display[i+18] = 0x200 + str[i];
        else {
            // End of string.  Pad with spaces.
            for(int j=i; j<16; j++)
                display[j+18] = 0x200 + ' ';
            break;
        }
    }
}

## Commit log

2025-01-30 Autotuner project
    [ECE 362 Final Project.kicad_pcb, ECE 362 Final Project.kicad_sch, ECX-.327-CDX-1293.step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]
2025-01-30 fixing format
    [ECE 362 Final Project.kicad_pcb, ECE 362 Final Project.kicad_sch, ECX-.327-CDX-1293.step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]
2025-01-30 Autotuner project on stm32
    Developed embedded DFT algorithm for real time auto-tuning. Initially FFT algorithm was too slow and unreliable.
    [ECE 362 Final Project.kicad_pcb, ECE 362 Final Project.kicad_sch, ECX-.327-CDX-1293.step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]
